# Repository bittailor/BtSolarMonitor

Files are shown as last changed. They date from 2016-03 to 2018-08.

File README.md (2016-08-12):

# IoT Solar Monitor





Work in progress for my [Open IoT Challenge 2.0 project](http://open-iot-challenge.bittailor.ch/edition/second/)

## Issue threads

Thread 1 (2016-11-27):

Solar Monitor

gokulshriyam, 2016-11-27:
Thanks for making such monitor board

I'm going to make a solar monitor board as part of my graduation project at college..!
Could you help me in redesigning this board again ?

I wanna to remove actuators, GSM module and inbuilt display system.

I want to measure inverter's measurement (Generation), Battery's measurement, Consumption measurement (load)  -   For ONGRID

I want to include ESP8266 feather to this board and make it WiFi enabled and API connected to thingspeak.

Could you help me in this regard ?

bittailor, 2016-11-30:
I'm not able to provide you support to design the monitor board for your graduation project. Feel free to fork my board design and adapt to your needs if it helps you. As far as I understood you would even remove most of the parts beside the current  monitor chips so it might be even simpler to start from scratch.

Also be aware that my board is not designed for large currents (max 10A) and voltages (max 15V). If you design a board for on grid system with inverters, chances are that you have to deal with larger currents and voltages and then the INA129 chip might not be the appropriate, you might need a Hall-Effect based sensor.

Closed 2016-11-30.

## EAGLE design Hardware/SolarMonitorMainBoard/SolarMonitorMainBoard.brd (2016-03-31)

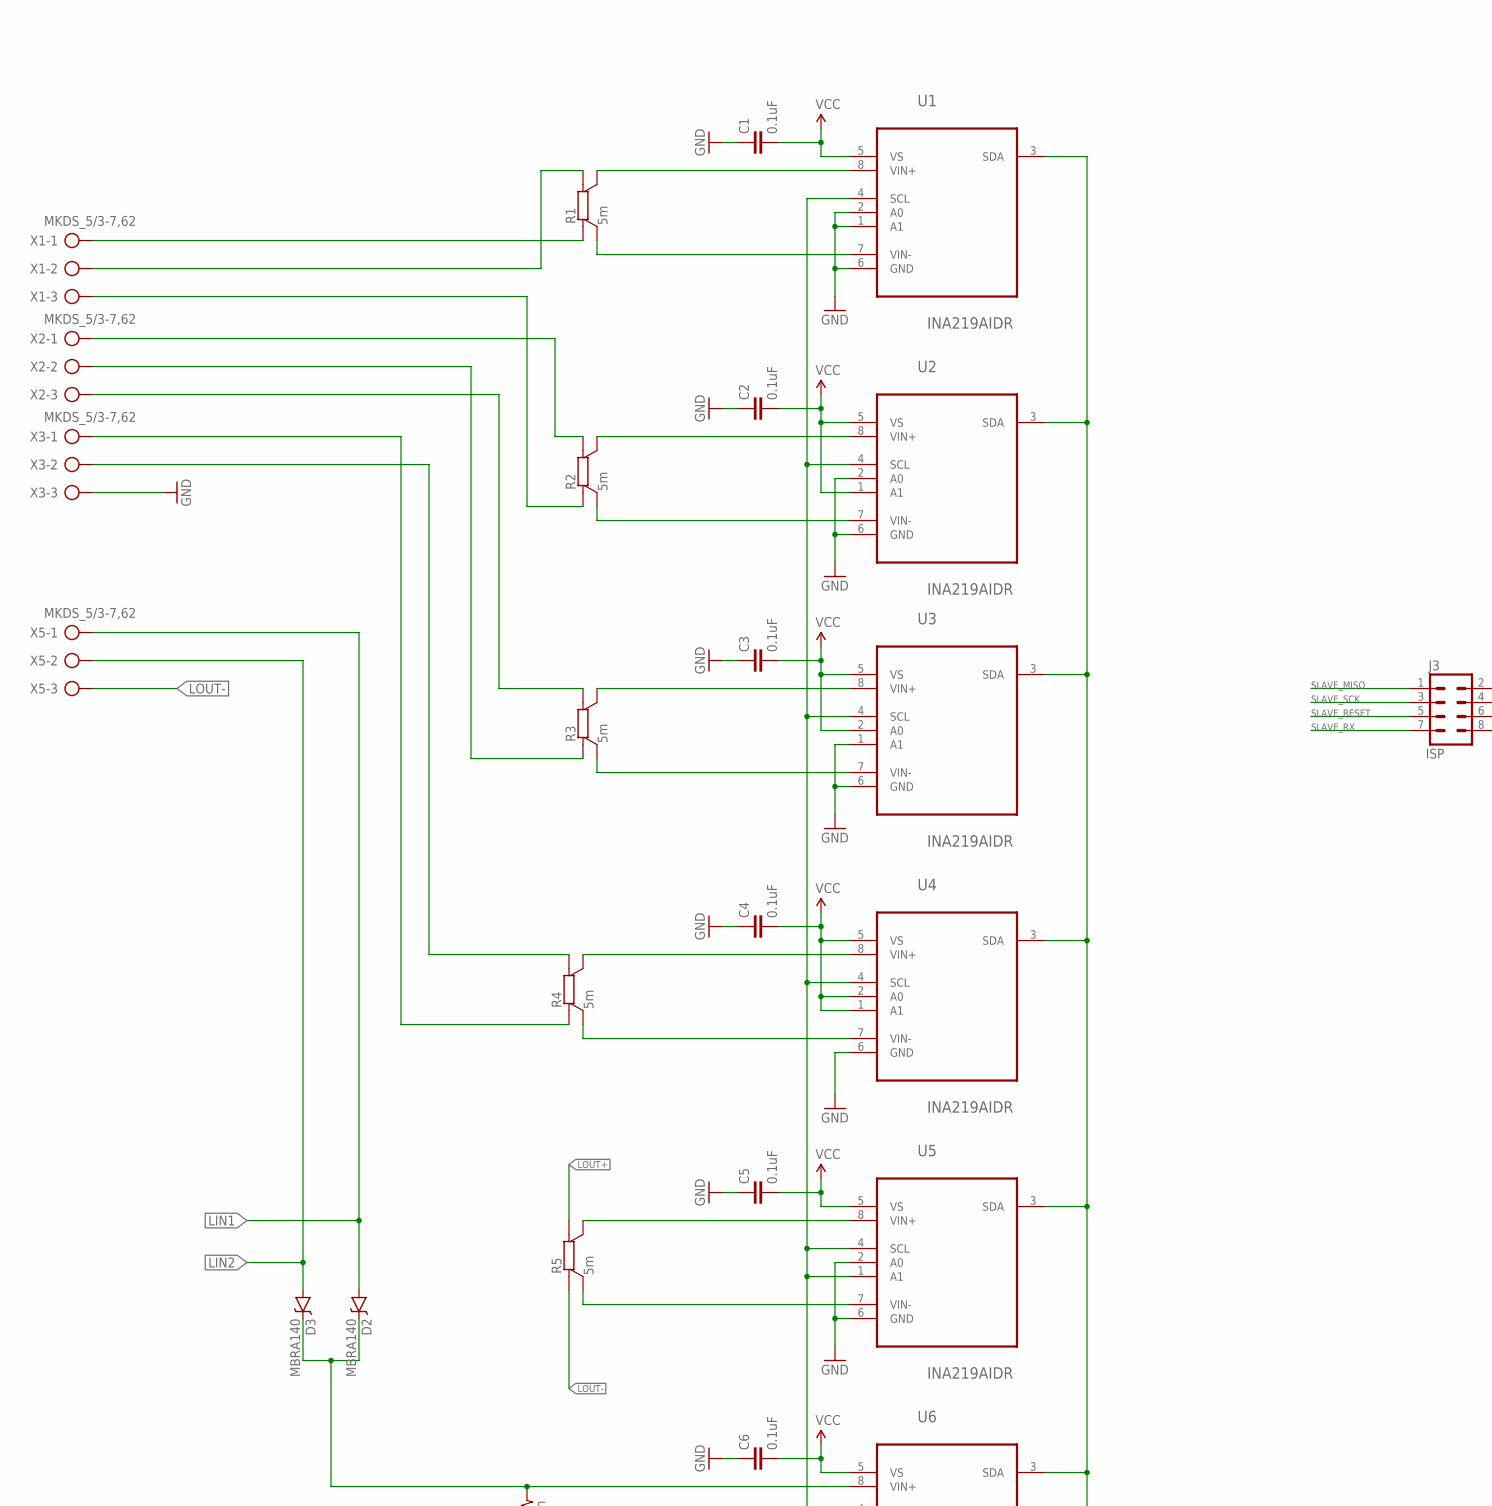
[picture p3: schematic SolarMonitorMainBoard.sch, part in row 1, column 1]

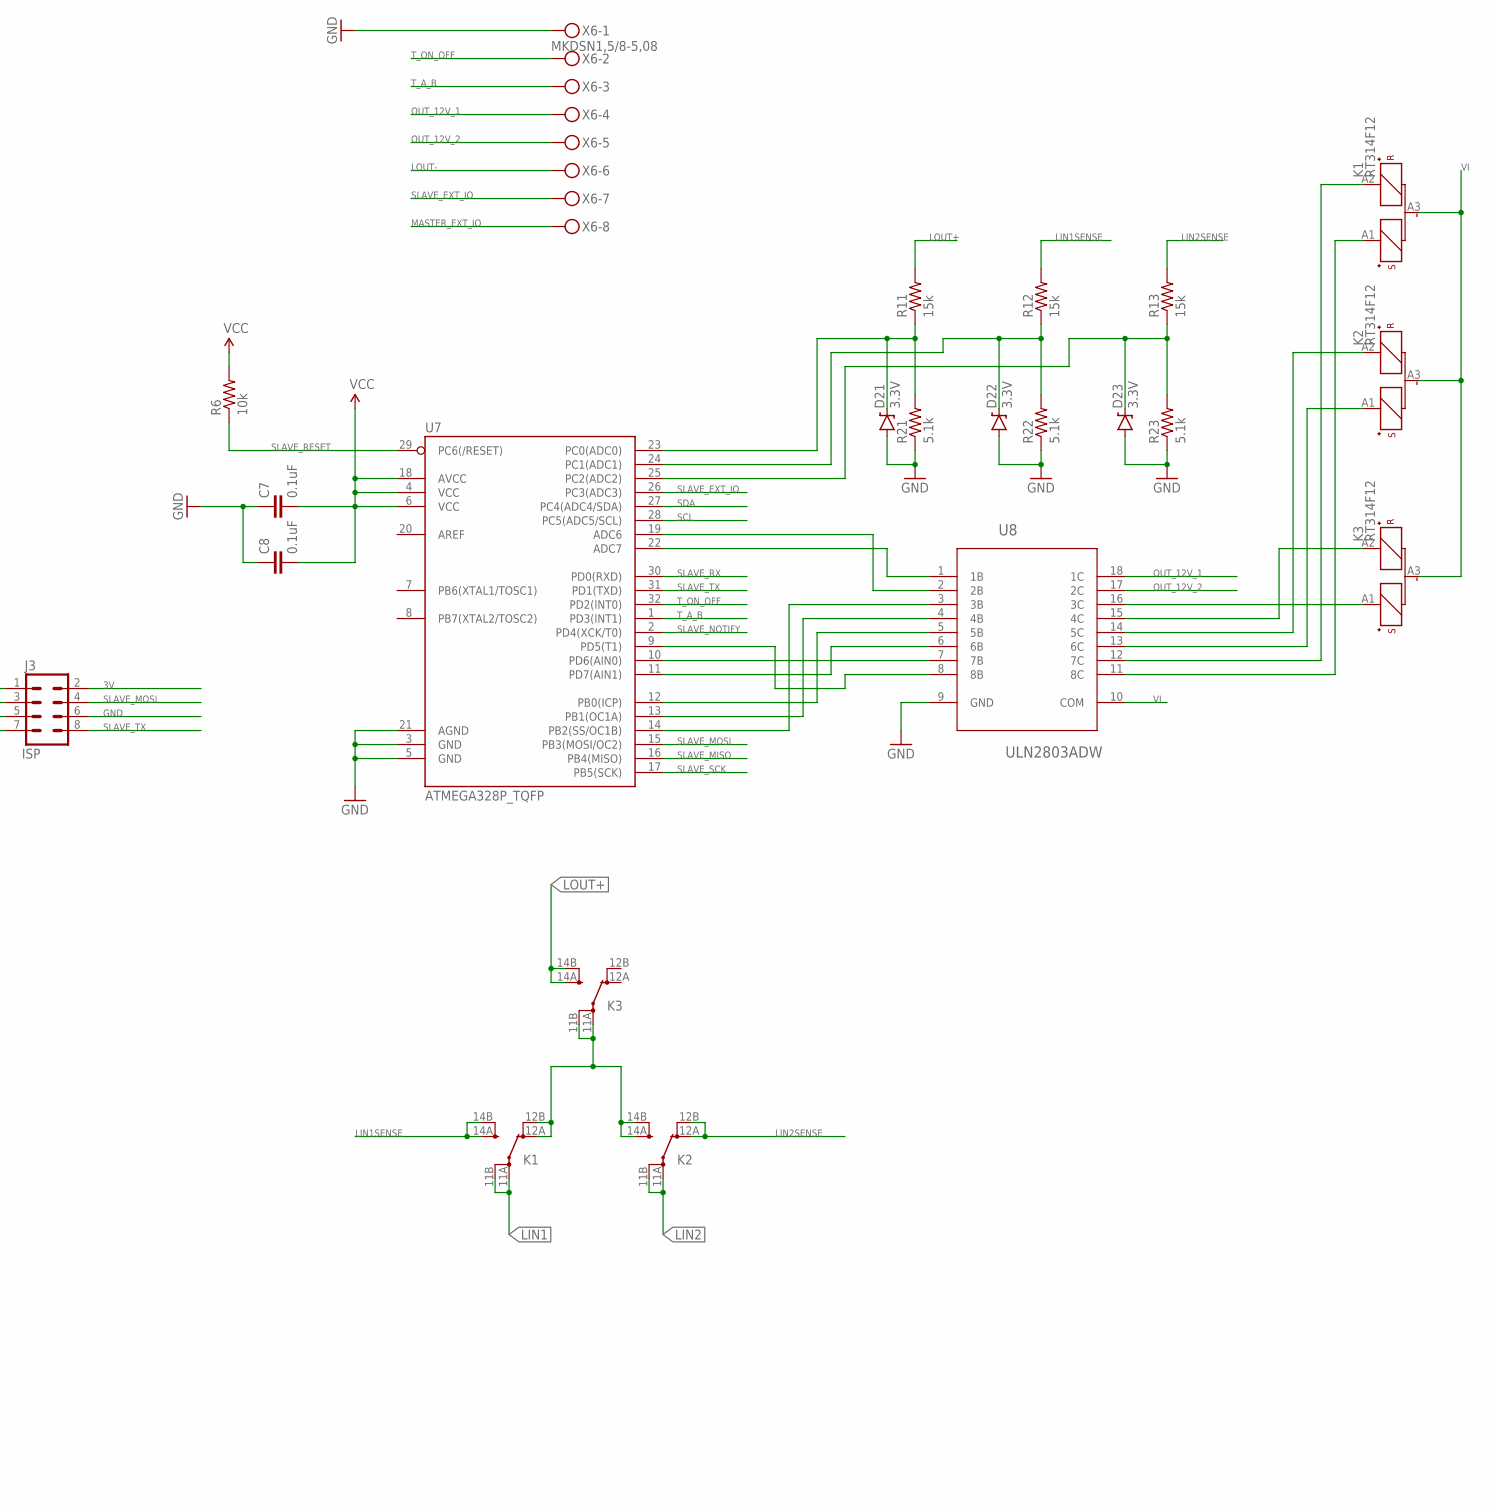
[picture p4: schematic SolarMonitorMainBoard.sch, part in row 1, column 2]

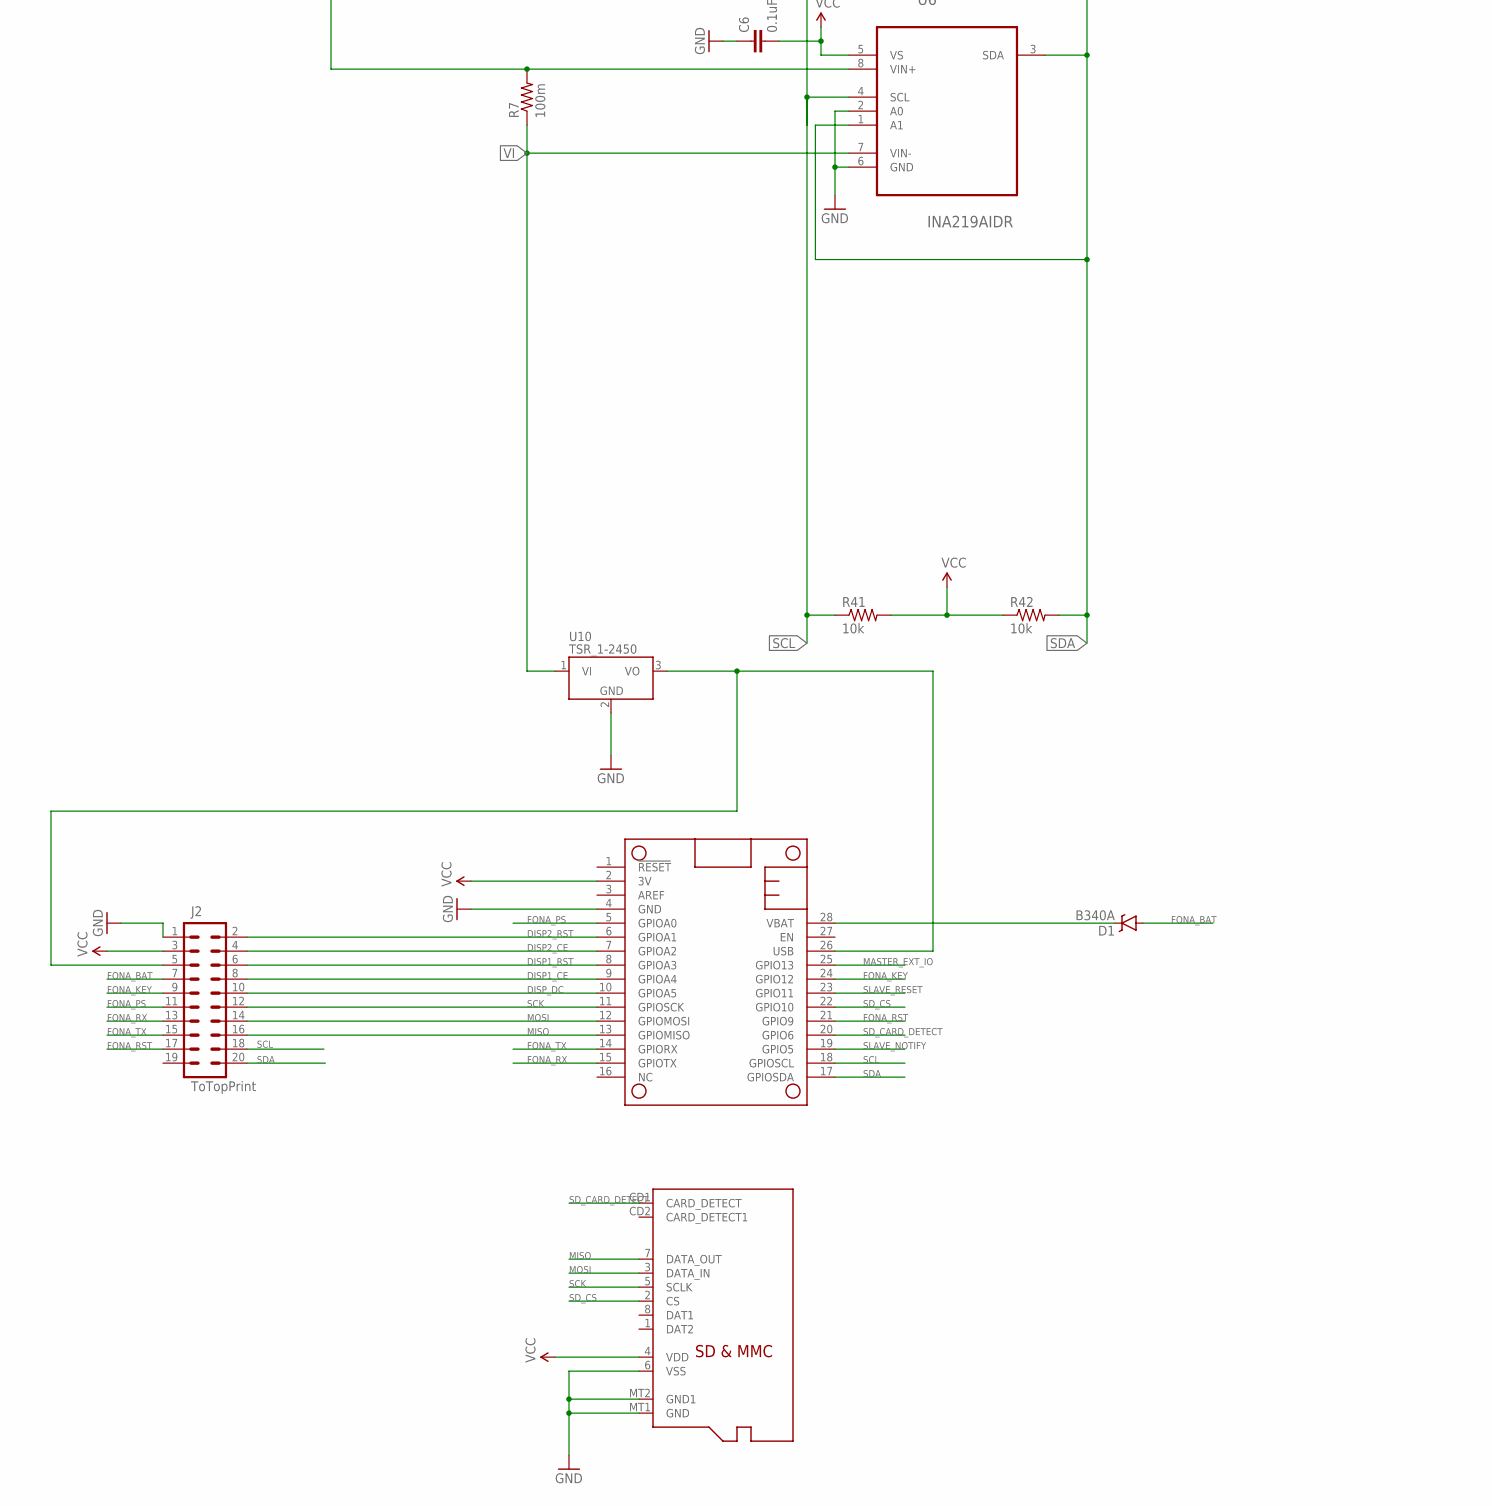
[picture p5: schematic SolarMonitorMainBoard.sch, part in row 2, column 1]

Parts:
C1, C2, C3, C4, C5, C6, C7, C8: 0.1uF; 0805
D1: B340A; SMA-DIODE
D2, D3: MBRA140; SMA-DIODE
D21, D22, D23: 3.3V; SOD-323
J2: ToTopPrint; 2X10
J3: ISP; 2X4
K1, K2, K3: RT314F12; RT1-BI
MS1: FEATHERWING_NODIM; FEATHERWING_DIM
R1, R2, R3, R4, R5: 5m; SMV
R6, R41, R42: 10k; 0805
R7: 100m; R2512
R11, R12, R13: 15k; 0805
R21, R22, R23: 5.1k; 0805
U1, U2, U3, U4, U5, U6: INA219AIDR; SOIC127P600X175-8N
U7: ATMEGA328P_TQFP; TQFP32-08
U8: ULN2803ADW; SOIC127P1030X265-18N
U10: TSR_1-2450; TSR-1
U$1: MICROSD
X1, X2, X3, X5: MKDS_5/3-7,62; MKDS_5/3-762
X6: MKDSN1,5/8-5,08

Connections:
1VIN+: R1.I1 (A), X1.2
1VIN-: R1.I2 (B), X1.1
3V: C1.2, C2.2, C3.2, C4.2, C5.2, C6.2, C7.2, C8.2, J2.3, J3.2, MS1.2 (3V), R6.2, R41.2, R42.1, U1.5 (VS), U2.1 (A1), U2.5 (VS), U3.2 (A0), U3.5 (VS), U4.1 (A1), U4.2 (A0), U4.5 (VS), U5.5 (VS), U6.5 (VS), U7.4 (VCC), U7.6 (VCC), U7.18 (AVCC), U$1.4 (VDD)
5V: J2.5, MS1.26 (USB), U10.3 (VO)
DISP1_CE: J2.8, MS1.9 (GPIOA4)
DISP1_RST: J2.6, MS1.8 (GPIOA3)
DISP2_CE: J2.4, MS1.7 (GPIOA2)
DISP2_RST: J2.2, MS1.6 (GPIOA1)
DISP_DC: J2.10, MS1.10 (GPIOA5)
FONA_BAT: D1.A, J2.7
FONA_KEY: J2.9, MS1.24 (GPIO12)
FONA_PS: J2.11, MS1.5 (GPIOA0)
FONA_RST: J2.17, MS1.21 (GPIO9)
FONA_RX: J2.13, MS1.15 (GPIOTX)
FONA_TX: J2.15, MS1.14 (GPIORX)
GND: C1.1, C2.1, C3.1, C4.1, C5.1, C6.1, C7.1, C8.1, D21.A, D22.A, D23.A, J2.1, J3.6, MS1.4 (GND), R21.1, R22.1, R23.1, U1.1 (A1), U1.2 (A0), U1.6 (GND), U2.2 (A0), U2.6 (GND), U3.1 (A1), U3.6 (GND), U4.6 (GND), U5.2 (A0), U5.6 (GND), U6.2 (A0), U6.6 (GND), U7.3 (GND), U7.5 (GND), U7.21 (AGND), U8.9 (GND), U10.2 (GND), U$1.6 (VSS), U$1.MT1 (GND), U$1.MT2 (GND1), X3.3, X6.1
LIN1: D2.A, K1.11A (PA), K1.11B (PB), X5.1
LIN1SENSE: K1.14A (SA), K1.14B (SB), R12.2
LIN2: D3.A, K2.11A (PA), K2.11B (PB), X5.2
LIN2SENSE: K2.12A (OA), K2.12B (OB), R13.2
LOUT+: K3.14A (SA), K3.14B (SB), R5.I1 (A), R11.2
LOUT-: R5.I2 (B), X5.3, X6.6
MASTER_EXT_IO: MS1.25 (GPIO13), X6.8
MISO: J2.16, MS1.13 (GPIOMISO), U$1.7 (DATA_OUT)
MOSI: J2.14, MS1.12 (GPIOMOSI), U$1.3 (DATA_IN)
unnamed: R2.I2 (B), X1.3
unnamed: D21.C, R11.1, R21.2, U7.23 (PC0(ADC0))
unnamed: U7.9 (PD5(T1)), U8.8 (8B)
unnamed: R2.I1 (A), X2.1
unnamed: R3.I1 (A), X2.3
unnamed: R3.I2 (B), X2.2
unnamed: R4.I2 (B), X3.1
unnamed: R4.I1 (A), X3.2
unnamed: D2.C, D3.C, R7.2, U6.8 (VIN+)
unnamed: U7.10 (PD6(AIN0)), U8.7 (7B)
unnamed: R2.U1 (SA), U2.8 (VIN+)
unnamed: R2.U2 (SB), U2.7 (VIN-)
unnamed: R1.U1 (SA), U1.8 (VIN+)
unnamed: R1.U2 (SB), U1.7 (VIN-)
unnamed: R3.U1 (SA), U3.8 (VIN+)
unnamed: R3.U2 (SB), U3.7 (VIN-)
unnamed: R4.U1 (SA), U4.8 (VIN+)
unnamed: R4.U2 (SB), U4.7 (VIN-)
unnamed: R5.U1 (SA), U5.8 (VIN+)
unnamed: R5.U2 (SB), U5.7 (VIN-)
unnamed: U7.11 (PD7(AIN1)), U8.6 (6B)
unnamed: K1.12A (OA), K1.12B (OB), K2.14A (SA), K2.14B (SB), K3.11A (PA), K3.11B (PB)
unnamed: U7.12 (PB0(ICP)), U8.5 (5B)
unnamed: U7.13 (PB1(OC1A)), U8.4 (4B)
unnamed: U7.14 (PB2(SS/OC1B)), U8.3 (3B)
unnamed: U7.22 (ADC7), U8.1 (1B)
unnamed: U7.19 (ADC6), U8.2 (2B)
unnamed: K2.A1 (S+), U8.13 (6C)
unnamed: K2.A2 (R+), U8.14 (5C)
unnamed: D22.C, R12.1, R22.2, U7.24 (PC1(ADC1))
unnamed: D23.C, R13.1, R23.2, U7.25 (PC2(ADC2))
unnamed: K3.A2 (R+), U8.15 (4C)
unnamed: K1.A2 (R+), U8.12 (7C)
unnamed: K1.A1 (S+), U8.11 (8C)
unnamed: K3.A1 (S+), U8.16 (3C)
OUT_12V_1: U8.18 (1C), X6.4
OUT_12V_2: U8.17 (2C), X6.5
SCK: J2.12, MS1.11 (GPIOSCK), U$1.5 (SCLK)
SCL: J2.18, MS1.18 (GPIOSCL), R41.1, U1.4 (SCL), U2.4 (SCL), U3.4 (SCL), U4.4 (SCL), U5.1 (A1), U5.4 (SCL), U6.4 (SCL), U7.28 (PC5(ADC5/SCL))
SDA: J2.20, MS1.17 (GPIOSDA), R42.2, U1.3 (SDA), U2.3 (SDA), U3.3 (SDA), U4.3 (SDA), U5.3 (SDA), U6.1 (A1), U6.3 (SDA), U7.27 (PC4(ADC4/SDA))
SD_CARD_DETECT: MS1.20 (GPIO6), U$1.CD1 (CARD_DETECT)
SD_CS: MS1.22 (GPIO10), U$1.2 (CS)
SLAVE_EXT_IO: U7.26 (PC3(ADC3)), X6.7
SLAVE_MISO: J3.1, U7.16 (PB4(MISO))
SLAVE_MOSI: J3.4, U7.15 (PB3(MOSI/OC2))
SLAVE_NOTIFY: MS1.19 (GPIO5), U7.2 (PD4(XCK/T0))
SLAVE_RESET: J3.5, MS1.23 (GPIO11), R6.1, U7.29 (PC6(/RESET))
SLAVE_RX: J3.7, U7.30 (PD0(RXD))
SLAVE_SCK: J3.3, U7.17 (PB5(SCK))
SLAVE_TX: J3.8, U7.31 (PD1(TXD))
T_A_B: U7.1 (PD3(INT1)), X6.3
T_ON_OFF: U7.32 (PD2(INT0)), X6.2
VBAT: D1.C, MS1.28 (VBAT)
VI: K1.A3 (-), K2.A3 (-), K3.A3 (-), R7.1, U6.7 (VIN-), U8.10 (COM), U10.1 (VI)

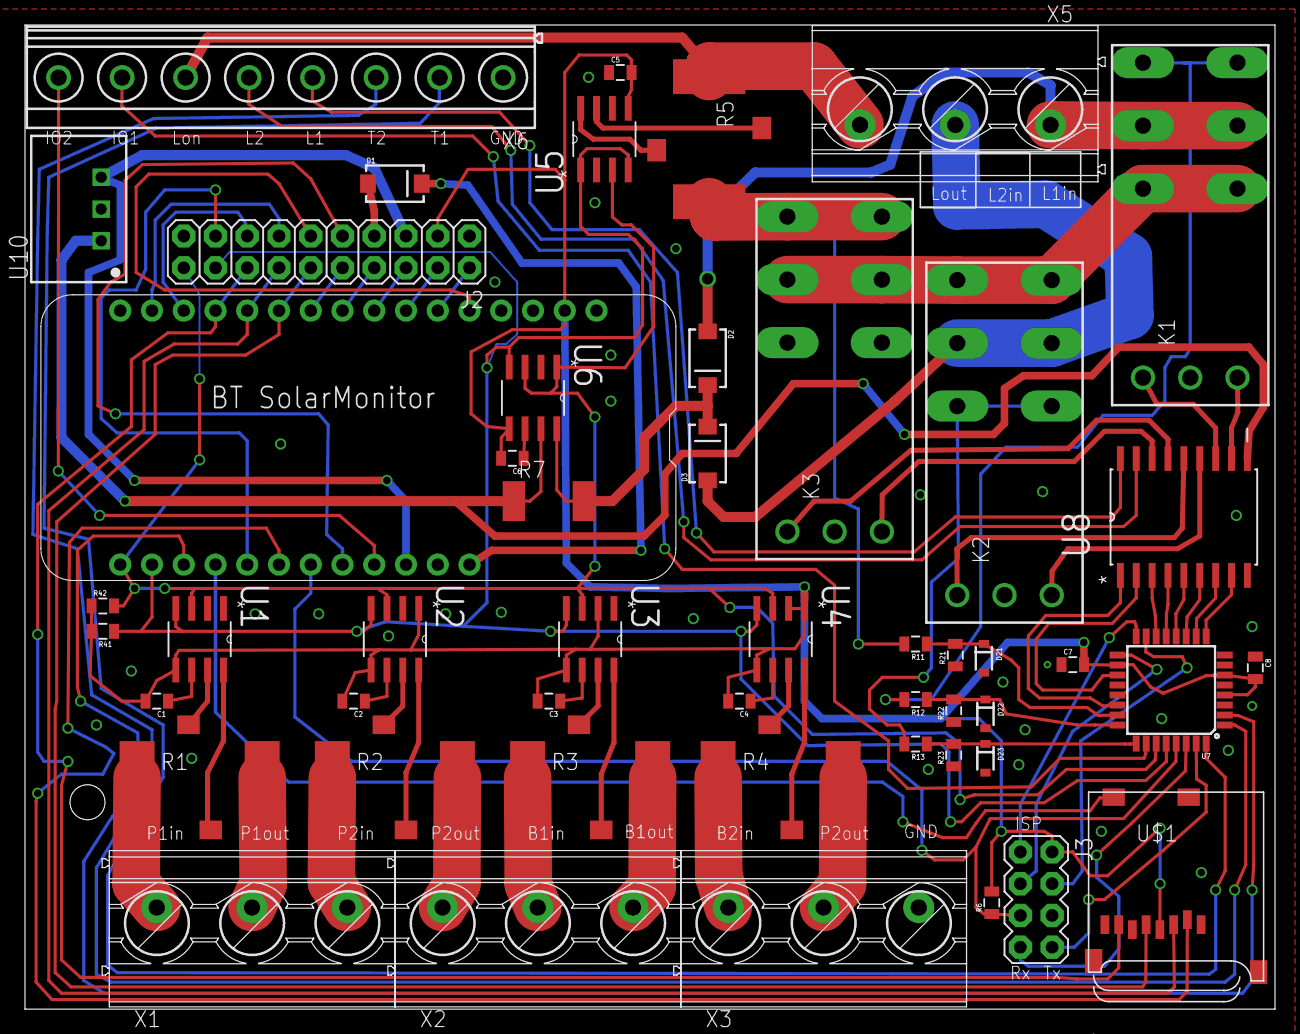
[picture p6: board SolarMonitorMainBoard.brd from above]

Board: 2 copper layers, 100.0 x 78.7 mm, 51 parts (1 on the bottom side), 79 nets.

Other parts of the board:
U$2: OSHW-LOGO-L

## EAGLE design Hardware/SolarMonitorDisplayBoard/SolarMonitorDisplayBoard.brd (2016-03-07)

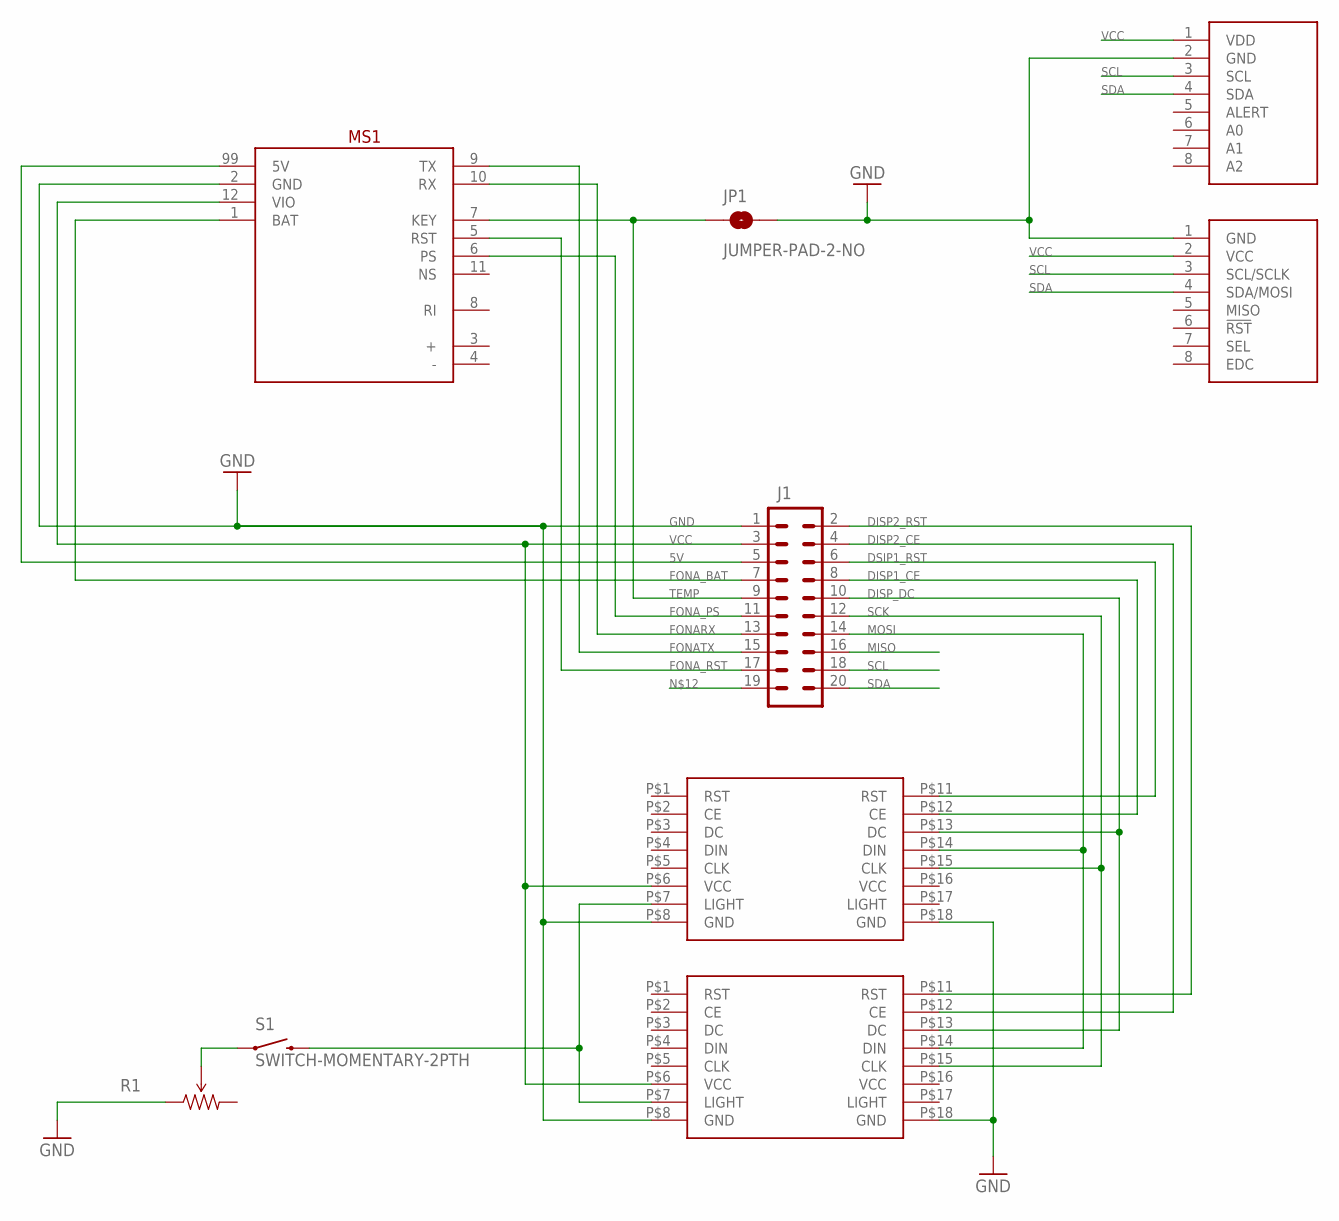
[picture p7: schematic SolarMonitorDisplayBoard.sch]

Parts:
BARO: T5403_BREAKOUT
J1: M10X2; 2X10
JP1: JUMPER-PAD-2-NO; PAD-JUMPER-2-NO_NO_SILK
MS1: FONA
R1: TRIMPOTPTH; TRIM_POT_PTH
S1: SWITCH-MOMENTARY-2PTH; TACTILE-PTH
TEMP: MCP9808_BREAKOUT
U$1, U$2: NOKIA_LCD_BREAKOUT

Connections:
5V: J1.5, MS1.99 (5V)
DISP1_CE: J1.8, U$2.P$12 (CE)
DISP2_CE: J1.4, U$1.P$12 (CE)
DISP2_RST: J1.2, U$1.P$11 (RST)
DISP_DC: J1.10, U$1.P$13 (DC), U$2.P$13 (DC)
DSIP1_RST: J1.6, U$2.P$11 (RST)
FONARX: J1.13, MS1.10 (RX)
FONATX: J1.15, MS1.9 (TX)
FONA_BAT: J1.7, MS1.1 (BAT)
FONA_PS: J1.11, MS1.6 (PS)
FONA_RST: J1.17, MS1.5 (RST)
GND: BARO.1 (GND), J1.1, JP1.2, MS1.2 (GND), R1.1 (CCW), TEMP.2 (GND), U$1.P$8 (GND), U$1.P$18 (GND), U$2.P$8 (GND), U$2.P$18 (GND)
MISO: J1.16
MOSI: J1.14, U$1.P$14 (DIN), U$2.P$14 (DIN)
unnamed: R1.2 (WIPER), S1.1
unnamed: S1.3 (2), U$1.P$7 (LIGHT), U$2.P$7 (LIGHT)
SCK: J1.12, U$1.P$15 (CLK), U$2.P$15 (CLK)
SCL: BARO.3 (SCL/SCLK), J1.18, TEMP.3 (SCL)
SDA: BARO.4 (SDA/MOSI), J1.20, TEMP.4 (SDA)
TEMP: J1.9, JP1.1, MS1.7 (KEY)
VCC: BARO.2 (VCC), J1.3, MS1.12 (VIO), TEMP.1 (VDD), U$1.P$6 (VCC), U$2.P$6 (VCC)

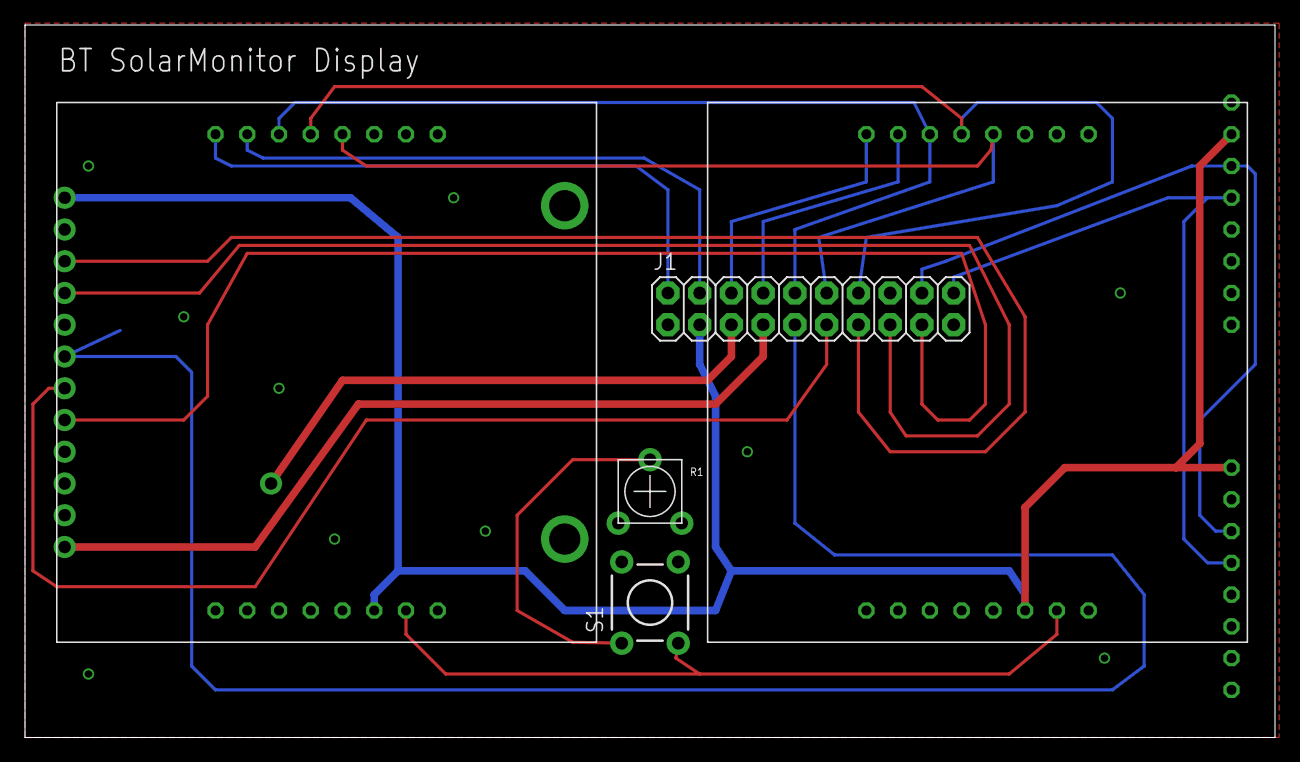
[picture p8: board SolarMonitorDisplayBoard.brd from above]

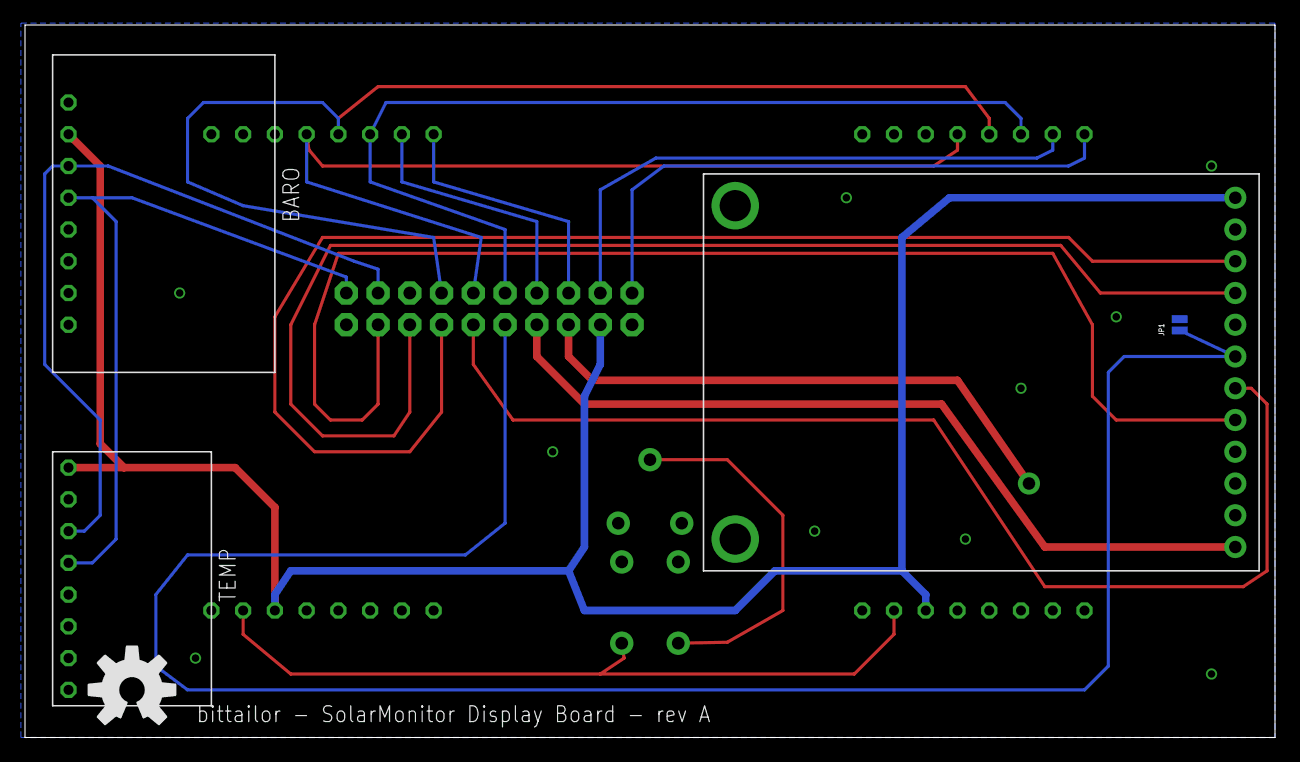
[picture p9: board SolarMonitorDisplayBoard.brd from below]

Board: 2 copper layers, 100.0 x 57.0 mm, 10 parts (5 on the bottom side), 20 nets.

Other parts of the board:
U$3: OSHW-LOGO-L

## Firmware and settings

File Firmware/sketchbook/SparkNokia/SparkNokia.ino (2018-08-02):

/* Nokia 5100 LCD Example Code
   Graphics driver and PCD8544 interface code for SparkFun's
   84x48 Graphic LCD.
   https://www.sparkfun.com/products/10168
 
  by: Jim Lindblom
    adapted from code by Nathan Seidle and mish-mashed with
    code from the ColorLCDShield.
  date: October 10, 2013
  license: Beerware. Feel free to use, reuse, and modify this
  code as you see fit. If you find it useful, and we meet someday,
  you can buy me a beer.
  
  This all-inclusive sketch will show off a series of graphics
  functions, like drawing lines, circles, squares, and text. Then
  it'll go into serial monitor echo mode, where you can type
  text into the serial monitor, and it'll be displayed on the
  LCD.
  
  This stuff could all be put into a library, but we wanted to
  leave it all in one sketch to keep it as transparent as possible.
  
  Hardware: (Note most of these pins can be swapped)
    Graphic LCD Pin ---------- Arduino Pin
       1-VCC       ----------------  5V
       2-GND       ----------------  GND
       3-SCE       ----------------  7
       4-RST       ----------------  6
       5-D/C       ----------------  5
       6-DN(MOSI)  ----------------  11
       7-SCLK      ----------------  13
       8-LED       - 330 Ohm res --  9
   The SCLK, DN(MOSI), must remain where they are, but the other 
   pins can be swapped. The LED pin should remain a PWM-capable
   pin. Don't forget to stick a current-limiting resistor in line
   between the LCD's LED pin and Arduino pin 9!
*/
#include <SPI.h> // We'll use SPI to transfer data. Faster!

/* PCD8544-specific defines: */
#define LCD_COMMAND  0 
#define LCD_DATA     1

/* 84x48 LCD Defines: */
#define LCD_WIDTH   84 // Note: x-coordinates go wide
#define LCD_HEIGHT  48 // Note: y-coordinates go high
#define WHITE       0  // For drawing pixels. A 0 draws white.
#define BLACK       1  // A 1 draws black.

/* Pin definitions: 
Most of these pins can be moved to any digital or analog pin.
DN(MOSI)and SCLK should be left where they are (SPI pins). The 
LED (backlight) pin should remain on a PWM-capable pin. */
const int scePin = A4;   // SCE - Chip select, pin 3 on LCD.
const int rstPin = A3;   // RST - Reset, pin 4 on LCD.
const int dcPin = A5;    // DC - Data/Command, pin 5 on LCD.
const int sdinPin = 23;  // DN(MOSI) - Serial data, pin 6 on LCD.
const int sclkPin = 24;  // SCLK - Serial clock, pin 7 on LCD.

/* Font table:
This table contains the hex values that represent pixels for a
font that is 5 pixels wide and 8 pixels high. Each byte in a row
represents one, 8-pixel, vertical column of a character. 5 bytes
per character. */
static const byte ASCII[][5] = {
  // First 32 characters (0x00-0x19) are ignored. These are
  // non-displayable, control characters.
   {0x00, 0x00, 0x00, 0x00, 0x00} // 0x20  
  ,{0x00, 0x00, 0x5f, 0x00, 0x00} // 0x21 !
  ,{0x00, 0x07, 0x00, 0x07, 0x00} // 0x22 "
  ,{0x14, 0x7f, 0x14, 0x7f, 0x14} // 0x23 #
  ,{0x24, 0x2a, 0x7f, 0x2a, 0x12} // 0x24 $
  ,{0x23, 0x13, 0x08, 0x64, 0x62} // 0x25 %
  ,{0x36, 0x49, 0x55, 0x22, 0x50} // 0x26 &
  ,{0x00, 0x05, 0x03, 0x00, 0x00} // 0x27 '
  ,{0x00, 0x1c, 0x22, 0x41, 0x00} // 0x28 (
  ,{0x00, 0x41, 0x22, 0x1c, 0x00} // 0x29 )
  ,{0x14, 0x08, 0x3e, 0x08, 0x14} // 0x2a *
  ,{0x08, 0x08, 0x3e, 0x08, 0x08} // 0x2b +
  ,{0x00, 0x50, 0x30, 0x00, 0x00} // 0x2c ,
  ,{0x08, 0x08, 0x08, 0x08, 0x08} // 0x2d -
  ,{0x00, 0x60, 0x60, 0x00, 0x00} // 0x2e .
  ,{0x20, 0x10, 0x08, 0x04, 0x02} // 0x2f /
  ,{0x3e, 0x51, 0x49, 0x45, 0x3e} // 0x30 0
  ,{0x00, 0x42, 0x7f, 0x40, 0x00} // 0x31 1
  ,{0x42, 0x61, 0x51, 0x49, 0x46} // 0x32 2
  ,{0x21, 0x41, 0x45, 0x4b, 0x31} // 0x33 3
  ,{0x18, 0x14, 0x12, 0x7f, 0x10} // 0x34 4
  ,{0x27, 0x45, 0x45, 0x45, 0x39} // 0x35 5
  ,{0x3c, 0x4a, 0x49, 0x49, 0x30} // 0x36 6
  ,{0x01, 0x71, 0x09, 0x05, 0x03} // 0x37 7
  ,{0x36, 0x49, 0x49, 0x49, 0x36} // 0x38 8
  ,{0x06, 0x49, 0x49, 0x29, 0x1e} // 0x39 9
  ,{0x00, 0x36, 0x36, 0x00, 0x00} // 0x3a :
  ,{0x00, 0x56, 0x36, 0x00, 0x00} // 0x3b ;
  ,{0x08, 0x14, 0x22, 0x41, 0x00} // 0x3c <
  ,{0x14, 0x14, 0x14, 0x14, 0x14} // 0x3d =
  ,{0x00, 0x41, 0x22, 0x14, 0x08} // 0x3e >
  ,{0x02, 0x01, 0x51, 0x09, 0x06} // 0x3f ?
  ,{0x32, 0x49, 0x79, 0x41, 0x3e} // 0x40 @
  ,{0x7e, 0x11, 0x11, 0x11, 0x7e} // 0x41 A
  ,{0x7f, 0x49, 0x49, 0x49, 0x36} // 0x42 B
  ,{0x3e, 0x41, 0x41, 0x41, 0x22} // 0x43 C
  ,{0x7f, 0x41, 0x41, 0x22, 0x1c} // 0x44 D
  ,{0x7f, 0x49, 0x49, 0x49, 0x41} // 0x45 E
  ,{0x7f, 0x09, 0x09, 0x09, 0x01} // 0x46 F
  ,{0x3e, 0x41, 0x49, 0x49, 0x7a} // 0x47 G
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
  ,{0x78, 0x46, 0x41, 0x46, 0x78} // 0x7f DEL
};

/* The displayMap variable stores a buffer representation of the
pixels on our display. There are 504 total bits in this array,
same as how many pixels there are on a 84 x 48 display.

Each byte in this array covers a 8-pixel vertical block on the 
display. Each successive byte covers the next 8-pixel column over
until you reach the right-edge of the display and step down 8 rows.

To update the display, we first have to write to this array, then
call the updateDisplay() function, which sends this whole array
to the PCD8544.

Because the PCD8544 won't let us write individual pixels at a 
time, this is how we can make targeted changes to the display. */
byte displayMap[LCD_WIDTH * LCD_HEIGHT / 8] = {
  0x00, 0x00, 0x00, 0x00, 0x00, 0x00, 0x00, 0x00, 0x00, 0x00, 0x00, 0x00, // (0,0)->(11,7) ~ These 12 bytes cover an 8x12 block in the left corner of the display 
  0x00, 0x00, 0x00, 0x00, 0x00, 0x00, 0x00, 0x00, 0x00, 0x00, 0x00, 0x00, // (12,0)->(23,7)
  0x00, 0x00, 0x00, 0x00, 0x00, 0x00, 0x00, 0x00, 0x00, 0x00, 0x00, 0xE0, // (24,0)->(35,7)
  0xF0, 0xF8, 0xFC, 0xFC, 0xFE, 0xFE, 0xFE, 0xFE, 0x1E, 0x0E, 0x02, 0x00, // (36,0)->(47,7)
  0x00, 0x00, 0x00, 0x00, 0x00, 0x00, 0x00, 0x00, 0x00, 0x00, 0x00, 0x00, // (48,0)->(59,7)
  0x00, 0x00, 0x00, 0x00, 0x00, 0x00, 0x00, 0x00, 0x00, 0x00, 0x00, 0x00, // (60,0)->(71,7)
  0x00, 0x00, 0x00, 0x00, 0x00, 0x00, 0x00, 0x00, 0x00, 0x00, 0x00, 0x00, // (72,0)->(83,7)
  0x00, 0x00, 0x00, 0x00, 0x00, 0x00, 0x00, 0x00, 0x00, 0x00, 0x00, 0x00, // (0,8)->(11,15)
  0x00, 0x00, 0x00, 0x00, 0x00, 0x00, 0x00, 0x00, 0x00, 0x00, 0x00, 0x00, // (12,8)->(23,15)
  0x00, 0x00, 0x00, 0x00, 0x00, 0x00, 0x00, 0x00, 0x00, 0x00, 0x00, 0x03, // (24,8)->(35,15)
  0x0F, 0x1F, 0x3F, 0x7F, 0xFF, 0xFF, 0xFF, 0xFF, 0xFF, 0xFE, 0xFC, 0xF8, // (36,8)->(47,15)
  0xF8, 0xF0, 0xF8, 0xFE, 0xFE, 0xFC, 0xF8, 0xE0, 0x00, 0x00, 0x00, 0x00, // (48,8)->(59,15)
  0x00, 0x00, 0x00, 0x00, 0x00, 0x00, 0x00, 0x00, 0x00, 0x00, 0x00, 0x00, // (60,8)->(71,15)
  0x00, 0x00, 0x00, 0x00, 0x00, 0x00, 0x00, 0x00, 0x00, 0x00, 0x00, 0x00, // (72,8)->(83,15)
  0x00, 0x00, 0x00, 0x00, 0x00, 0x00, 0x00, 0x00, 0x00, 0x00, 0x00, 0x00, // (0,16)->(11,23)
  0x00, 0x00, 0x00, 0x00, 0x00, 0x00, 0x00, 0x00, 0x00, 0x00, 0x00, 0x00, // (12,16)->(23,23)
  0x00, 0x00, 0xF8, 0xFC, 0xFE, 0xFE, 0xFF, 0xFF, 0xF3, 0xE0, 0xE0, 0xC0, // (24,16)->(35,23)
  0xC0, 0xC0, 0xE0, 0xE0, 0xF1, 0xFF, 0xFF, 0xFF, 0xFF, 0xFF, 0xFF, 0xFF, // (36,16)->(47,23)
  0xFF, 0xFF, 0xFF, 0xFF, 0xFF, 0xFF, 0xFF, 0xFF, 0x3E, 0x00, 0x00, 0x00, // (48,16)->(59,23)
  0x00, 0x00, 0x00, 0x00, 0x00, 0x00, 0x00, 0x00, 0x00, 0x00, 0x00, 0x00, // (60,16)->(71,23)
  0x00, 0x00, 0x00, 0x00, 0x00, 0x00, 0x00, 0x00, 0x00, 0x00, 0x00, 0x00, // (72,16)->(83,23)
  0x00, 0x00, 0x00, 0x00, 0x00, 0x00, 0x00, 0x00, 0x00, 0x00, 0x00, 0x00, // (0,24)->(11,31)
  0x00, 0x00, 0x00, 0x00, 0x00, 0x00, 0x00, 0x00, 0x00, 0x00, 0x00, 0x00, // (12,24)->(23,31)
  0x00, 0x00, 0xFF, 0xFF, 0xFF, 0xFF, 0xFF, 0xFF, 0xFF, 0xFF, 0xFF, 0xFF, // (24,24)->(35,31)
  0xFF, 0xFF, 0xFF, 0xFF, 0xFF, 0xFF, 0xFF, 0xFF, 0xFF, 0xFF, 0xFF, 0xFF, // (36,24)->(47,31)
  0xFF, 0xFF, 0xFF, 0x7F, 0x3F, 0x1F, 0x07, 0x01, 0x00, 0x00, 0x00, 0x00, // (48,24)->(59,31)
  0x00, 0x00, 0x00, 0x00, 0x00, 0x00, 0x00, 0x00, 0x00, 0x00, 0x00, 0x00, // (60,24)->(71,31)
  0x00, 0x00, 0x00, 0x00, 0x00, 0x00, 0x00, 0x00, 0x00, 0x00, 0x00, 0x00, // (72,24)->(83,31)
  0x00, 0x00, 0x00, 0x00, 0x00, 0x00, 0x00, 0x00, 0x00, 0x00, 0x00, 0x00, // (0,32)->(11,39)
  0x00, 0x00, 0x00, 0x00, 0x00, 0x00, 0x00, 0x00, 0x00, 0x00, 0x00, 0x00, // (12,32)->(23,39)
  0x00, 0x00, 0xFF, 0xFF, 0xFF, 0xFF, 0xFF, 0xFF, 0xFF, 0x7F, 0x3F, 0x1F, // (24,32)->(35,39)
  0x0F, 0x0F, 0x0F, 0x07, 0x07, 0x07, 0x07, 0x07, 0x07, 0x07, 0x03, 0x03, // (36,32)->(47,39)
  0x01, 0x01, 0x00, 0x00, 0x00, 0x00, 0x00, 0x00, 0x00, 0x00, 0x00, 0x00, // (48,32)->(59,39)
  0x00, 0x00, 0x00, 0x00, 0x00, 0x00, 0x00, 0x00, 0x00, 0x00, 0x00, 0x00, // (60,32)->(71,39)
  0x00, 0x00, 0x00, 0x00, 0x00, 0x00, 0x00, 0x00, 0x00, 0x00, 0x00, 0x00, // (72,32)->(83,39)
  0x00, 0x00, 0x00, 0x00, 0x00, 0x00, 0x00, 0x00, 0x00, 0x00, 0x00, 0x00, // (0,40)->(11,47)
  0x00, 0x00, 0x00, 0x00, 0x00, 0x00, 0x00, 0x00, 0x00, 0x00, 0x00, 0x00, // (12,40)->(23,47)
  0x00, 0x00, 0x3F, 0x1F, 0x0F, 0x07, 0x03, 0x01, 0x00, 0x00, 0x00, 0x00, // (24,40)->(35,47)
  0x00, 0x00, 0x00, 0x00, 0x00, 0x00, 0x00, 0x00, 0x00, 0x00, 0x00, 0x00, // (36,40)->(47,47)
  0x00, 0x00, 0x00, 0x00, 0x00, 0x00, 0x00, 0x00, 0x00, 0x00, 0x00, 0x00, // (48,40)->(59,47)
  0x00, 0x00, 0x00, 0x00, 0x00, 0x00, 0x00, 0x00, 0x00, 0x00, 0x00, 0x00, // (60,40)->(71,47)
  0x00, 0x00, 0x00, 0x00, 0x00, 0x00, 0x00, 0x00, 0x00, 0x00, 0x00, 0x00, // (72,40)->(83,47) !!! The bottom right pixel!
};

/* This array is the same size as the displayMap. We'll use it
as an example of how to draw a bitmap. xkcd comic transposing
makes for an excellent display application.
For reference, see: http://xkcd.com/149/ */
char xkcdSandwich[504] = {
0xFF, 0x8D, 0x9F, 0x13, 0x13, 0xF3, 0x01, 0x01, 0xF9, 0xF9, 0x01, 0x81, 0xF9, 0xF9, 0x01, 0xF1,
0xF9, 0x09, 0x09, 0xFF, 0xFF, 0xF1, 0xF9, 0x09, 0x09, 0xF9, 0xF1, 0x01, 0x01, 0x01, 0x01, 0x01,
0xF9, 0xF9, 0x09, 0xF9, 0x09, 0xF9, 0xF1, 0x01, 0xC1, 0xE9, 0x29, 0x29, 0xF9, 0xF1, 0x01, 0xFF,
0xFF, 0x71, 0xD9, 0x01, 0x01, 0xF1, 0xF9, 0x29, 0x29, 0xB9, 0xB1, 0x01, 0x01, 0x01, 0xF1, 0xF1,
0x11, 0xF1, 0xF1, 0xF1, 0xE1, 0x01, 0xE1, 0xF1, 0x51, 0x51, 0x71, 0x61, 0x01, 0x01, 0xC1, 0xF1,
0x31, 0x31, 0xF1, 0xFF, 0xFF, 0x00, 0x01, 0x01, 0x01, 0x01, 0x60, 0xE0, 0xA0, 0x01, 0x01, 0x81,
0xE1, 0x61, 0x60, 0xC0, 0x01, 0xE1, 0xE1, 0x21, 0x21, 0xE0, 0xC1, 0x01, 0xC1, 0xE1, 0x20, 0x20,
0xFC, 0xFC, 0xE0, 0xE0, 0xC1, 0xE1, 0xE0, 0xC1, 0xE0, 0xE1, 0x01, 0xFC, 0xFC, 0x21, 0x21, 0xE1,
0xC1, 0xE5, 0xE4, 0x01, 0xC1, 0xE0, 0x20, 0x21, 0x20, 0x00, 0x01, 0xFD, 0xFD, 0x21, 0x20, 0xE0,
0x00, 0x00, 0x01, 0x01, 0xC0, 0x61, 0x31, 0x31, 0x21, 0x20, 0xC0, 0x81, 0x01, 0x01, 0x01, 0x00,
0x00, 0x00, 0x00, 0x01, 0x01, 0x01, 0x01, 0xFF, 0xFF, 0x00, 0x00, 0x00, 0x00, 0x01, 0x03, 0x02,
0x03, 0x01, 0x00, 0x01, 0x03, 0xF2, 0x1A, 0x0B, 0x08, 0x0B, 0x1B, 0x10, 0x60, 0xE3, 0x03, 0x00,
0x01, 0x03, 0x02, 0x02, 0x03, 0x03, 0x00, 0x03, 0x03, 0x00, 0x00, 0x03, 0x03, 0x00, 0x00, 0x03,
0x03, 0x00, 0x00, 0x03, 0x03, 0x03, 0x03, 0x00, 0x01, 0x03, 0x02, 0x02, 0x03, 0x01, 0x00, 0x03,
0x03, 0x00, 0x00, 0x03, 0x00, 0x00, 0x00, 0x3E, 0x63, 0x80, 0x80, 0x80, 0x80, 0x60, 0x3F, 0x07,
0x00, 0x00, 0x00, 0x00, 0x00, 0x00, 0x00, 0x00, 0x00, 0x00, 0x00, 0xFF, 0xFF, 0x00, 0x00, 0x00,
0x00, 0x00, 0x00, 0x00, 0xFE, 0x01, 0x01, 0x01, 0x02, 0x03, 0x3E, 0xE8, 0xF8, 0xF0, 0xD0, 0x90,
0x18, 0x0F, 0x00, 0x00, 0x00, 0x00, 0x00, 0x00, 0x00, 0x00, 0x00, 0x00, 0x00, 0x00, 0x00, 0x00,
0x00, 0x00, 0x00, 0x00, 0x00, 0x00, 0x00, 0x00, 0x00, 0x00, 0x00, 0x00, 0x00, 0x00, 0x00, 0x00,
0x00, 0x00, 0x00, 0x00, 0x00, 0x00, 0x00, 0x00, 0x00, 0x00, 0x00, 0x00, 0x00, 0xC0, 0x38, 0xFF,
0x0C, 0x38, 0xE0, 0x80, 0x00, 0x00, 0x00, 0x00, 0x00, 0x00, 0x00, 0x00, 0x00, 0x00, 0x00, 0xFF,
0xFF, 0x00, 0x00, 0x00, 0x00, 0x00, 0x00, 0x00, 0x1F, 0xF0, 0x00, 0x00, 0x00, 0x00, 0x00, 0x33,
0x5F, 0x8F, 0x84, 0x05, 0x07, 0x06, 0x0C, 0x0E, 0x0E, 0x0C, 0x14, 0x34, 0x68, 0x88, 0xD8, 0x70,
0x00, 0x00, 0x00, 0x00, 0x00, 0xE0, 0x10, 0x10, 0x10, 0xF0, 0xE0, 0x00, 0xF0, 0xF0, 0x00, 0x80,
0x80, 0x00, 0x00, 0x80, 0x80, 0x80, 0x80, 0x00, 0x80, 0x80, 0x00, 0x80, 0x00, 0x00, 0x20, 0x38,
0x0E, 0x01, 0xC0, 0x3F, 0xE0, 0x00, 0x00, 0x03, 0x0E, 0x08, 0x00, 0x00, 0x00, 0x00, 0x00, 0x00,
0x00, 0x00, 0x00, 0xFF, 0xFF, 0x80, 0x80, 0x80, 0x80, 0x80, 0x80, 0x80, 0xB6, 0xED, 0xC0, 0xC0,
0xC0, 0xE0, 0xA0, 0xA0, 0xA0, 0xA0, 0xA1, 0xA1, 0xA1, 0xA1, 0xA1, 0xA1, 0xA1, 0xE1, 0xE1, 0xC1,
0xEF, 0xBB, 0x83, 0x86, 0x88, 0xB0, 0x80, 0x80, 0x80, 0x8F, 0x90, 0x90, 0x90, 0x9F, 0x8F, 0x80,
0x9F, 0x9F, 0x87, 0x8D, 0x98, 0x80, 0x8C, 0x9E, 0x92, 0x92, 0x9F, 0xC0, 0xC7, 0xFF, 0xB8, 0x8F,
0x80, 0x90, 0x90, 0xC0, 0xF0, 0x8E, 0x81, 0x80, 0x81, 0x8F, 0xB8, 0xE0, 0x80, 0x80, 0x80, 0x80,
0x80, 0x80, 0x80, 0x80, 0x80, 0x80, 0x80, 0xFF, 
};

void setup()
{
  Serial.begin(9600);

  lcdBegin(); // This will setup our pins, and initialize the LCD
  updateDisplay(); // with displayMap untouched, SFE logo
  setContrast(40); // Good values range from 40-60
  delay(2000);
  
  lcdFunTime(); // Runs a 30-second demo of graphics functions
  
  // Wait for serial to come in, then clear display and go to echo
  while (!Serial.available())
    ;
  clearDisplay(WHITE);
  updateDisplay();
}

// Loop turns the display into a local serial monitor echo.
// Type to the Arduino from the serial monitor, and it'll echo
// what you type on the display. Type ~ to clear the display.
void loop()
{
  static int cursorX = 0;
  static int cursorY = 0;
  
  if (Serial.available())
  {
    char c = Serial.read();
    
    switch (c)
    {
    case '\n': // New line
      cursorY += 8;
      break;
    case '\r': // Return feed
      cursorX = 0;
      break;
    case '~': // Use ~ to clear the screen.
      clearDisplay(WHITE);
      updateDisplay();
      cursorX = 0; // reset the cursor
      cursorY = 0;
      break;
    default:
      setChar(c, cursorX, cursorY, BLACK);
      updateDisplay();
      cursorX += 6; // Increment cursor
      break;
    }
    // Manage cursor
    if (cursorX >= (LCD_WIDTH - 4)) 
    { // If the next char will be off screen...
      cursorX = 0; // ... reset x to 0...
      cursorY += 8; // ...and increment to next line.
      if (cursorY >= (LCD_HEIGHT - 7))
      { // If the next line takes us off screen...
        cursorY = 0; // ...go back to the top.
      }
    }
  }
}

/* This function serves as a fun demo of the graphics driver
functions below. */
void lcdFunTime()
{
  clearDisplay(WHITE); // Begin by clearing the display
  randomSeed(analogRead(A0));
  
  /* setPixel Example */
  const int pixelCount = 100;
  for (int i=0; i<pixelCount; i++)
  {
    // setPixel takes 2 to 3 parameters. The first two params
    // are x and y variables. The third optional variable is
    // a "color" boolean. 1 for black, 0 for white.
    // setPixel() with two variables will set the pixel with
    // the color set to black.
    // clearPixel() will call setPixel with with color set to
    // white.
    setPixel(random(0, LCD_WIDTH), random(0, LCD_HEIGHT));
    // After drawing something, we must call updateDisplay()
    // to actually make the display draw something new.
    updateDisplay();
    delay(10);
  }
  setStr("full of stars", 0, LCD_HEIGHT-8, BLACK);
  updateDisplay();
  delay(1000);
  // Seizure time!!! Err...demoing invertDisplay()
  for (int i=0; i<5; i++)
  {
    invertDisplay(); // This will swap all bits in our display
    delay(200);
    invertDisplay(); // This will get us back to where we started
    delay(200);
  }
  delay(2000);
  
  /* setLine Example */
  clearDisplay(WHITE); // Start fresh
  int x0 = LCD_WIDTH/2;
  int y0 = LCD_HEIGHT/2;
  for (float i=0; i<2*PI; i+=PI/8)
  {
    // Time to whip out some maths:
    const int lineLength = 24;
    int x1 = x0 + lineLength * sin(i);
    int y1 = y0 + lineLength * cos(i);
    
    // setLine(x0, y0, x1, y1, bw) takes five variables. The
    // first four are coordinates for the start and end of the 
    // line. The last variable is the color (1=black, 0=white).
    setLine(x0, y0, x1, y1, BLACK);
    updateDisplay();
    delay(100);
  }
  
  
  /* setRect Example */
  clearDisplay(WHITE); // Start fresh
  
  // setRect takes six parameters (x0, y0, x1, y0, fill, bw)
  // x0, y0, x1, and y0 are the two diagonal corner coordinates
  // fill is a boolean, which determines if the rectangle is
  // filled in. bw determines the color 0=white, 1=black.
  for (int x=0; x<LCD_WIDTH; x+=8)
  { // Swipe right black
    setRect(0, 0, x, LCD_HEIGHT, 1, BLACK);
    updateDisplay();
    delay(10);
  }
  for (int x=0; x<LCD_WIDTH; x+=8)
  { // Swipe right white
    setRect(0, 0, x, LCD_HEIGHT, 1, WHITE);
    updateDisplay();
    delay(10);
  }
  for (int x=0; x<12; x++)
  { // Shutter swipe
    setRect(0, 0, x, LCD_HEIGHT, 1, 1);
    setRect(11, 0, x+12, LCD_HEIGHT, 1, BLACK);
    setRect(23, 0, x+24, LCD_HEIGHT, 1, BLACK);
    setRect(35, 0, x+36, LCD_HEIGHT, 1, BLACK);
    setRect(47, 0, x+48, LCD_HEIGHT, 1, BLACK);
    setRect(59, 0, x+60, LCD_HEIGHT, 1, BLACK);
    setRect(71, 0, x+72, LCD_HEIGHT, 1, BLACK);
    updateDisplay();
    delay(10);
  }
  // 3 Dee!
  setRect(25, 10, 45, 30, 0, WHITE);
  setRect(35, 20, 55, 40, 0, WHITE);
  setLine(25, 10, 35, 20, WHITE);
  setLine(45, 30, 55, 40, WHITE);
  setLine(25, 30, 35, 40, WHITE);
  setLine(45, 10, 55, 20, WHITE);
  updateDisplay();
  delay(2000);
  
  /* setCircle Example */
  clearDisplay(WHITE);
  // setCircle takes 5 parameters -- x0, y0, radius, bw, and
  // lineThickness. x0 and y0 are the center coords of the circ.
  // radius is the...radius. bw is the color (0=white, 1=black)
  // lineThickness is the line width of the circle, 1 = smallest
  // thickness moves in towards center.
  for (int i=0; i<20; i++)
  {
    int x = random(0, LCD_WIDTH);
    int y = random(0, LCD_HEIGHT);
    
    setCircle(x, y, i, BLACK, 1);
    updateDisplay();
    delay(100);
  }
  delay(2000);
  
  /* setChar & setStr Example */
  // setStr takes 4 parameters: an array of characters to print,
  // x and y coordinates for the top-left corner. And a color
  setStr("Modern Art", 0, 10, WHITE);
  updateDisplay();
  delay(2000);
  
  /* setBitmap Example */
  // setBitmap takes one parameter, an array of the same size
  // as our screen.
  setBitmap(xkcdSandwich);
  updateDisplay();
}


// Because I keep forgetting to put bw variable in when setting...
void setPixel(int x, int y)
{
  setPixel(x, y, BLACK); // Call setPixel with bw set to Black
}

void clearPixel(int x, int y)
{
  setPixel(x, y, WHITE); // call setPixel with bw set to white
}

// This function sets a pixel on displayMap to your preferred
// color. 1=Black, 0= white.
void setPixel(int x, int y, boolean bw)
{
  // First, double check that the coordinate is in range.
  if ((x >= 0) && (x < LCD_WIDTH) && (y >= 0) && (y < LCD_HEIGHT))
  {
    byte shift = y % 8;
  
    if (bw) // If black, set the bit.
      displayMap[x + (y/8)*LCD_WIDTH] |= 1<<shift;
    else   // If white clear the bit.
      displayMap[x + (y/8)*LCD_WIDTH] &= ~(1<<shift);
  }
}

// setLine draws a line from x0,y0 to x1,y1 with the set color.
// This function was grabbed from the SparkFun ColorLCDShield 
// library.
void setLine(int x0, int y0, int x1, int y1, boolean bw)
{
  int dy = y1 - y0; // Difference between y0 and y1
  int dx = x1 - x0; // Difference between x0 and x1
  int stepx, stepy;

  if (dy < 0)
  {
    dy = -dy;
    stepy = -1;
  }
  else
    stepy = 1;

  if (dx < 0)
  {
    dx = -dx;
    stepx = -1;
  }
  else
    stepx = 1;

  dy <<= 1; // dy is now 2*dy
  dx <<= 1; // dx is now 2*dx
  setPixel(x0, y0, bw); // Draw the first pixel.

  if (dx > dy) 
  {
    int fraction = dy - (dx >> 1);
    while (x0 != x1)
    {
      if (fraction >= 0)
      {
        y0 += stepy;
        fraction -= dx;
      }
      x0 += stepx;
      fraction += dy;
      setPixel(x0, y0, bw);
    }
  }
  else
  {
    int fraction = dx - (dy >> 1);
    while (y0 != y1)
    {
      if (fraction >= 0)
      {
        x0 += stepx;
        fraction -= dy;
      }
      y0 += stepy;
      fraction += dx;
      setPixel(x0, y0, bw);
    }
  }
}

// setRect will draw a rectangle from x0,y0 top-left corner to
// a x1,y1 bottom-right corner. Can be filled with the fill
// parameter, and colored with bw.
// This function was grabbed from the SparkFun ColorLCDShield
// library.
void setRect(int x0, int y0, int x1, int y1, boolean fill, boolean bw)
{
  // check if the rectangle is to be filled
  if (fill == 1)
  {
    int xDiff;

    if(x0 > x1)
      xDiff = x0 - x1; //Find the difference between the x vars
    else
      xDiff = x1 - x0;

    while(xDiff > 0)
    {
      setLine(x0, y0, x0, y1, bw);

      if(x0 > x1)
        x0--;
      else
        x0++;

      xDiff--;
    }
  }
  else 
  {
    // best way to draw an unfilled rectangle is to draw four lines
    setLine(x0, y0, x1, y0, bw);
    setLine(x0, y1, x1, y1, bw);
    setLine(x0, y0, x0, y1, bw);
    setLine(x1, y0, x1, y1, bw);
  }
}

// setCircle draws a circle centered around x0,y0 with a defined
// radius. The circle can be black or white. And have a line
// thickness ranging from 1 to the radius of the circle.
// This function was grabbed from the SparkFun ColorLCDShield 
// library.
void setCircle (int x0, int y0, int radius, boolean bw, int lineThickness)
{
  for(int r = 0; r < lineThickness; r++)
  {
    int f = 1 - radius;
    int ddF_x = 0;
    int ddF_y = -2 * radius;
    int x = 0;
    int y = radius;

    setPixel(x0, y0 + radius, bw);
    setPixel(x0, y0 - radius, bw);
    setPixel(x0 + radius, y0, bw);
    setPixel(x0 - radius, y0, bw);

    while(x < y)
    {
      if(f >= 0)
      {
        y--;
        ddF_y += 2;
        f += ddF_y;
      }
      x++;
      ddF_x += 2;
      f += ddF_x + 1;

      setPixel(x0 + x, y0 + y, bw);
      setPixel(x0 - x, y0 + y, bw);
      setPixel(x0 + x, y0 - y, bw);
      setPixel(x0 - x, y0 - y, bw);
      setPixel(x0 + y, y0 + x, bw);
      setPixel(x0 - y, y0 + x, bw);
      setPixel(x0 + y, y0 - x, bw);
      setPixel(x0 - y, y0 - x, bw);
    }
    radius--;
  }
}
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

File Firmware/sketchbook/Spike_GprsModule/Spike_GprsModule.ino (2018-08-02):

#define FONA_KEY 12
#define FONA_PS A0
#define FONA_RST 9

#include <BtMcuCore.h>
#include <BtMcuNet.h>
#include <MQTTClient.h>

#include <Bt/Core/Logger.hpp>
#include <Bt/Core/Time.hpp>
#include <Bt/Core/DigitalOut.hpp>
#include <Bt/Core/DigitalIn.hpp>
#include <Bt/Core/Workcycle.hpp>
#include <Bt/Core/StaticStringBuilder.hpp>
#include <Bt/Core/PeriodicCallback.hpp>
#include <Bt/Net/Gprs/MobileTerminal.hpp>
#include <Bt/Net/Gprs/GprsModule.hpp>

#include "Spike_GprsModule_Settings.settings.hpp"

const size_t COMMAND_BUFFER_SIZE = 200;
char sCommandBuffer[COMMAND_BUFFER_SIZE] = {0};
bool sRunning = true;
Bt::Core::StaticStringBuilder sCommandBuilder(sCommandBuffer, COMMAND_BUFFER_SIZE);

using namespace Bt;

class PahoTimer {
   public:

      PahoTimer() : mInterval(0), mStart(millis()) {
      }

      PahoTimer(int ms) : mInterval(ms), mStart(millis()) {
      }


      bool expired() {
         return (millis() - mStart) >= mInterval;
      }

      void countdown_ms(unsigned long ms) {
         mInterval = ms;
         mStart = millis();
      }
      void countdown(int seconds) {
         countdown_ms(((unsigned long)seconds) * 1000L);
      }

      int left_ms() {
         unsigned long delay = millis() - mStart;
         if(delay >= mInterval) {
            return 0;
         }
         return mInterval - delay;
      }

   private:
      unsigned long mInterval;
      unsigned long mStart;

};

Core::Time sTime;
Core::DigitalOut sOnOffKey(FONA_KEY);
Core::DigitalOut sReset(FONA_RST);
Core::DigitalIn sPowerState(FONA_PS);
Net::Gprs::MobileTerminal sMobileTerminal(Serial1);
Net::Gprs::GprsModule sGprsModule(sGprsModuleSettings, sTime,sOnOffKey,sReset,sPowerState,sMobileTerminal);
MQTT::Client<Net::Gprs::I_GprsClient, PahoTimer, 500> sMqttClient(sGprsModule);
Core::Workcycle sWorkcycle;


void handleAction(MQTT::MessageData& pMessageData) {
   MQTT::Message& message = pMessageData.message;
   char payload[message.payloadlen + 1];
   memcpy(payload,message.payload,message.payloadlen);
   payload[message.payloadlen] = 0;
   Serial.print("Message ");
   Serial.print(" arrived: qos ");
   Serial.print(message.qos);
   Serial.print(", retained ");
   Serial.print(message.retained);
   Serial.print(", dup ");
   Serial.print(message.dup);
   Serial.print(", packetid ");
   Serial.println(message.id);
   Serial.print("Payload ");
   Serial.println(payload);
}

class Listener : public Net::Gprs::GprsModule::I_Listener {
   public:
      virtual void stateChanged(Net::Gprs::GprsModule::State pState) {
         LOG("stateChanged " << static_cast<int>(pState));
      }

      virtual void onReady() {
         const char * url = MQTT_BROKER;

         int rc = sGprsModule.connect(url,1883);
         if(rc!= 0) {
            LOG("tcp connect failed with " << rc);
         }
      }

      virtual void onConnected() {
         MQTTPacket_connectData data = MQTTPacket_connectData_initializer;
         data.MQTTVersion = 3;
         data.clientID.cstring = (char*)MQTT_CLIENT_ID;
         data.keepAliveInterval = 120;
         data.willFlag = true;
         data.will.topicName.cstring = (char*)"device/state";
         data.will.message.cstring = (char*)"offline";
         data.will.retained = true;
         data.will.qos = MQTT::QOS1;
         data.username.cstring = (char*)MQTT_USERNAME;
         data.password.cstring = (char*)MQTT_PASSWORD;

         int rc = sMqttClient.connect(data);
         if (rc != 0)
         {
            LOG("!!! mqtt connect failed "  << rc);
            sGprsModule.disconnect();
            return;
         }
         LOG("MQTT connected");
         sMqttClient.subscribe("spike/action", MQTT::QOS1, &handleAction);

         rc = publish("device/state","online",MQTT::QOS1,true);
         LOG("MQTT publish returned " << rc);
         mConnected = true;
      }

      virtual void onDisconnected() {
         mConnected = false;
      }

      void publishTime(){
         if(mConnected){
            sMobileTerminal.disableSleepMode();
            sMqttClient.yield(1);
            char msg[30];
            Core::StaticStringBuilder builder(msg,30);
            builder.print(millis());
            int rc = publish("spike/millis",msg, MQTT::QOS1);
            if(rc != 0) {
               LOG("!!! MQTT publish failed " << rc);
            } else {
               LOG("MQTT publish success ");
            }
            sMqttClient.yield(10);
            sMobileTerminal.enableSleepMode();

         }
      }

      int publish(const char* pTopicName, const char* pMessage, MQTT::QoS pQos, bool pRetained = false) {
         LOG("MQTT publish " << pTopicName << " - " << pMessage << " [" << strlen(pMessage) << "]" );
         return sMqttClient.publish(pTopicName, (void*)pMessage, strlen(pMessage), pQos, pRetained);
      }

      bool mConnected = false;

};

Listener sListener;

//Core::PeriodicCallback sYield(sTime,500,Core::Function<void()>::build<Listener,&Listener::yield>(sListener));
Core::PeriodicCallback sPublish(sTime,50000,Core::Function<void()>::build<Listener,&Listener::publishTime>(sListener));

void setup() {
   pinMode(13, OUTPUT);
   digitalWrite(13, HIGH);
   while (!Serial) {}
   Serial.begin(115200);
   Serial.println(F("** Spike GPRS Module**"));
   Serial1.begin(9600);
   digitalWrite(13, LOW);
   delay(1000);


   sWorkcycle.add(sGprsModule);
   sWorkcycle.add(sPublish);

   sOnOffKey.begin();
   sReset.begin();
   sPowerState.begin();
   sGprsModule.begin(sListener);
}

void loop() {
   sWorkcycle.oneWorkcycle();
   //sMqttClient.yield(10);

   while(Serial.available()) {
      char c = Serial.read();
      if(c == '\n') {
         executeCommand(sCommandBuffer);
         sCommandBuilder.clear();
      } else {
         Serial.print(" ++ Append '");
         Serial.print(c);
         Serial.println("'");
         sCommandBuilder.print(c);
      }
   }

}

void executeCommand(const char* pCommand) {
   if(strcmp("s",pCommand)==0) {
      shutdown();
   }else if(strcmp("shutdown",pCommand)==0) {
      shutdown();
   } else {
      Serial.print("Unknown command: '");
      Serial.print(pCommand);
      Serial.println("'");
   }
}

void shutdown() {
   sRunning = false;
   Serial.println("start shutdown ...");
   sMqttClient.disconnect();
   sGprsModule.disconnect();
   sMobileTerminal.powerDown();
   Serial.println("... shutdown done");
   while (true) {
      Serial.println("Ready to reboot ...");
      delay(2000);
   }
}

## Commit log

2016-02-15 reorganize folder structure
    [BtSolarMonitor.brd, BtSolarMonitor.sch]
2016-02-15 Rename main board
    [SolarMonitorMainBoard.brd, SolarMonitorMainBoard.sch]
2016-02-15 Work in progress on the main board ...
    [SolarMonitorMainBoard.brd, SolarMonitorMainBoard.sch]
2016-02-15 Update schematic
    [SolarMonitorMainBoard.brd, SolarMonitorMainBoard.sch]
2016-02-15 Lets hope
    [SolarMonitorMainBoard.brd, SolarMonitorMainBoard.sch]
2016-02-15 Before autoroute try
    [SolarMonitorMainBoard.brd, SolarMonitorMainBoard.sch]
2016-02-17 Schematic done. Lets route ...
    [SolarMonitorMainBoard.brd, SolarMonitorMainBoard.sch]
2016-02-17 Some Routing
    [SolarMonitorMainBoard.brd, SolarMonitorMainBoard.sch]
2016-02-17 Fix checks
    [SolarMonitorMainBoard.brd]
2016-02-18 More routing
    [SolarMonitorMainBoard.brd, SolarMonitorMainBoard.sch]
2016-02-18 All routed. Let's check.
    [SolarMonitorMainBoard.brd, SolarMonitorMainBoard.sch]
2016-02-18 Fix Warnings ADD I2C to header
    [SolarMonitorMainBoard.brd, SolarMonitorMainBoard.sch]
2016-02-19 Replace BAT schottky with SMA part.
    [SolarMonitorMainBoard.brd, SolarMonitorMainBoard.sch]
2016-02-20 Schematic for display PCB
    [SolarMonitorDisplayBoard.brd, SolarMonitorDisplayBoard.sch]
2016-02-20 Add some labels.
    [SolarMonitorDisplayBoard.brd, SolarMonitorDisplayBoard.sch, SolarMonitorMainBoard.brd]
2016-02-22 Add trim pot and button for background light.
    [SolarMonitorDisplayBoard.brd, SolarMonitorDisplayBoard.sch]
2016-03-07 Work in progress.
    [SolarMonitorDisplayBoard.brd, SolarMonitorMainBoard.brd]
2016-03-31 Fix ground instead of +12V error in schematic routing on board not done yet.
    [SolarMonitorMainBoard.brd, SolarMonitorMainBoard.sch]
2016-03-31 Skip the arduino stuff till host test run
2016-03-31 Revert to running stage
2016-04-16 Continue implement
    - SlaveController
    - CurrentSensors
2016-04-21 Implement the master controller and slave I2C
2016-04-21 First attend for I2C with sleep
2016-04-21 sleeping slave that works with I2C
2016-07-25 Currently only working for the target
2016-08-12 Also filter linux system headers for coverage
2016-10-21 Send battery state to IO slave
2016-10-22 Change ON-OFF button logic to be a switch instead of a push-button

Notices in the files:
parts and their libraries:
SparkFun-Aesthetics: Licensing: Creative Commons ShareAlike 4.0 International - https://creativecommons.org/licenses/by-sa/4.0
